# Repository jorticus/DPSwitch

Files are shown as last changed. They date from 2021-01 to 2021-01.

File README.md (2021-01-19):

# DPSwitch #

*License: CERN-OHL-S v2*

DPSwitch is a simple KVM-style device that allows you to switch Display Port & USB2.0 between two source devices (eg. a Laptop and a PC):

Mux Diagram

It is built around the HD3SS215 DP/HDMI mux chip by Texas Instruments, and has a simple flip-flop circuit and two physical buttons to select the input to route to the output. No firmware is required!

I abuse the HD3SS215's HDMI DDC lines to switch USB2.0 signals, and while the datasheet doesn't specify a maximum bandwidth for these lines, it appears to work fine. This avoids the need for a separate mux to switch USB.

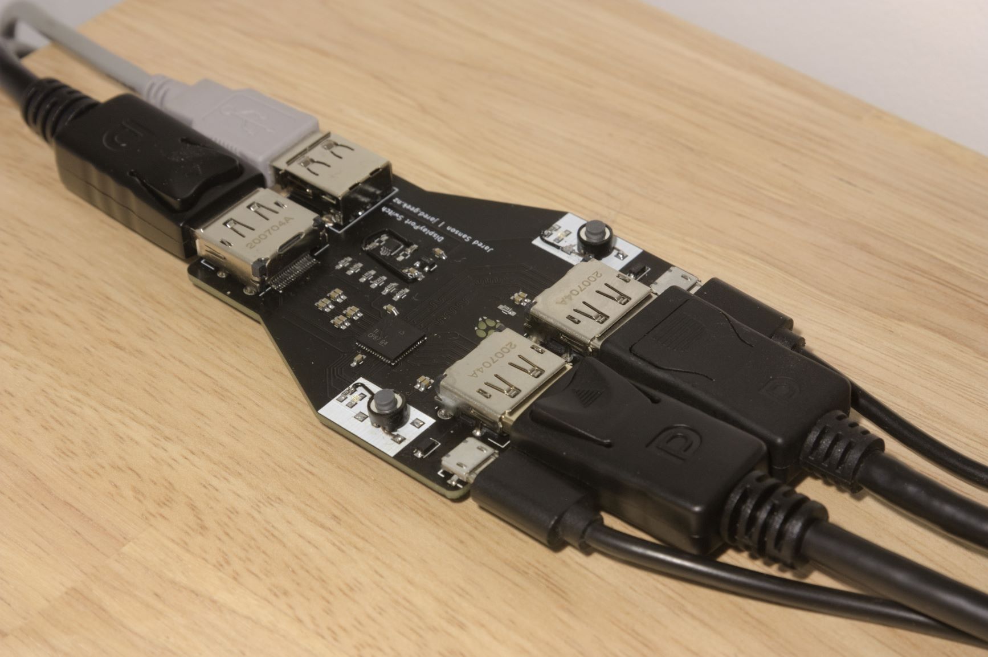
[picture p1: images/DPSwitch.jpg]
Rev1 Prototype


## Bill of Materials ##

Qty | Description               | Part Number
----|---------------------------|------------
  1 | DP/HDMI 2:1 Mux 6Gbps     | HD3SS215RTQT
  1 | Dual NAND Gate            | 74LVC2G00DC,125
  1 | 0603 Side look LED (Blue) | KPA-1606QBC-D
  2 | 0603 SMD LED (Green)      | 
  2 | Button (SMD)              | PTS645*
  1 | USB Type-A Conn (TH)      | SS-52100-001
  2 | Micro USB Conn (SMD)      | 609-5379-2-ND 
  2 | Diode                     | BAT54GWJ
  3 | DisplayPort Conn          | MOLEX 47272-0001

Plus various 0603 resistors & capacitors. See schematic.

## Manufacturing ##

Since DP operates in the GHz range, the PCB must be impedance controlled, and utilizes a 4 layer stackup. I used JLCPCB's 4-layer '[JLC7628](https://jlcpcb.com/quote/pcbOrderFaq/PCB%20Stackup)' PCB with a dielectric constant of 4.6, and a black solder mask.

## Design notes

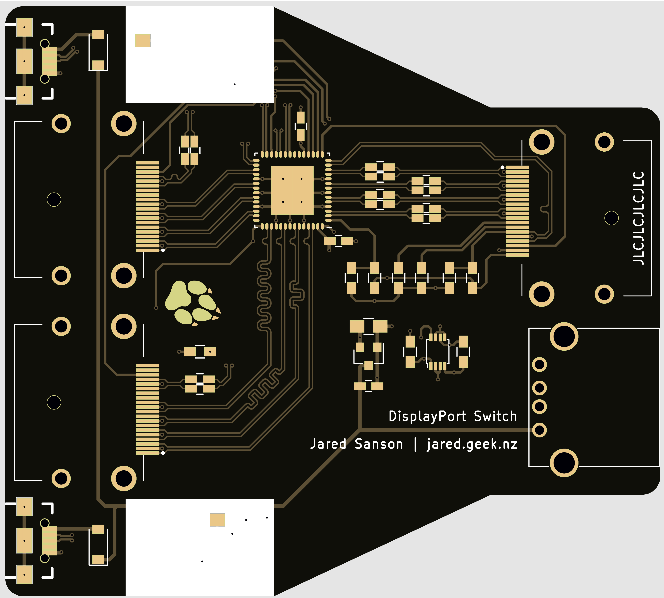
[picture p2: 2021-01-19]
pcb-front.png

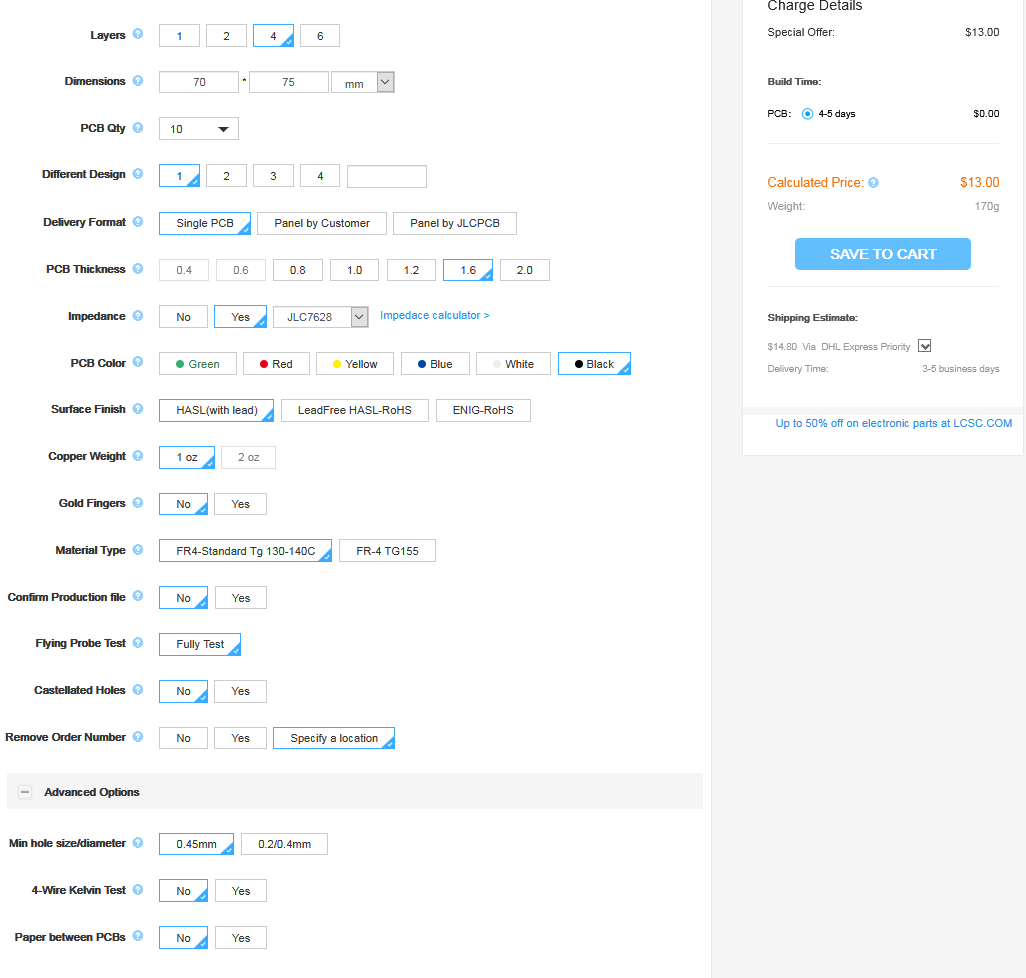
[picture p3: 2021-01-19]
JLCPCB Quote.png

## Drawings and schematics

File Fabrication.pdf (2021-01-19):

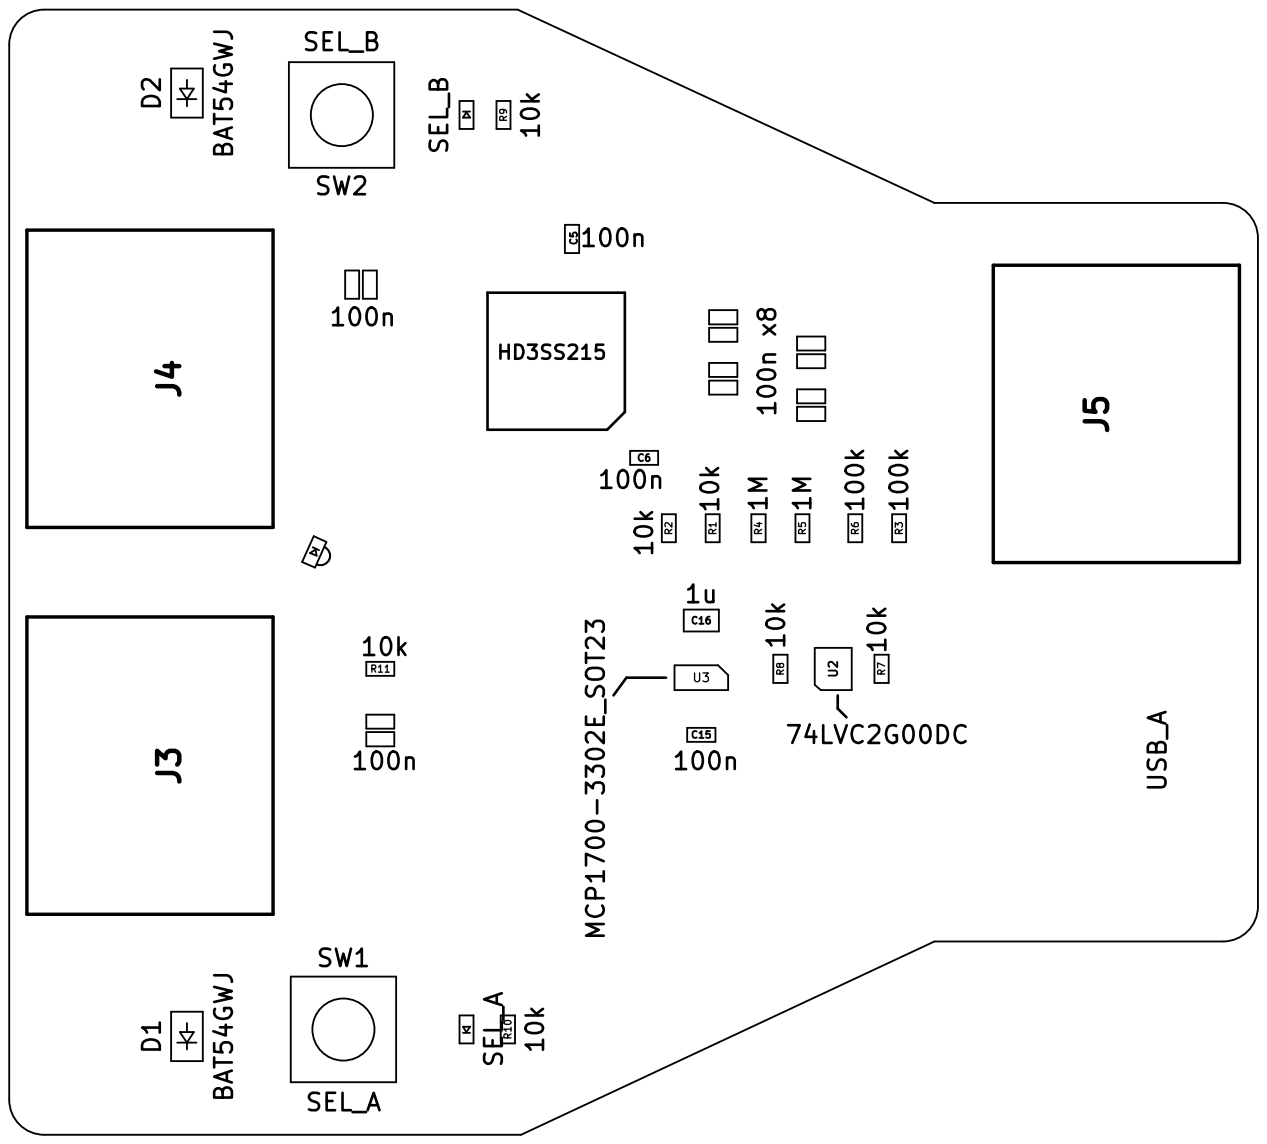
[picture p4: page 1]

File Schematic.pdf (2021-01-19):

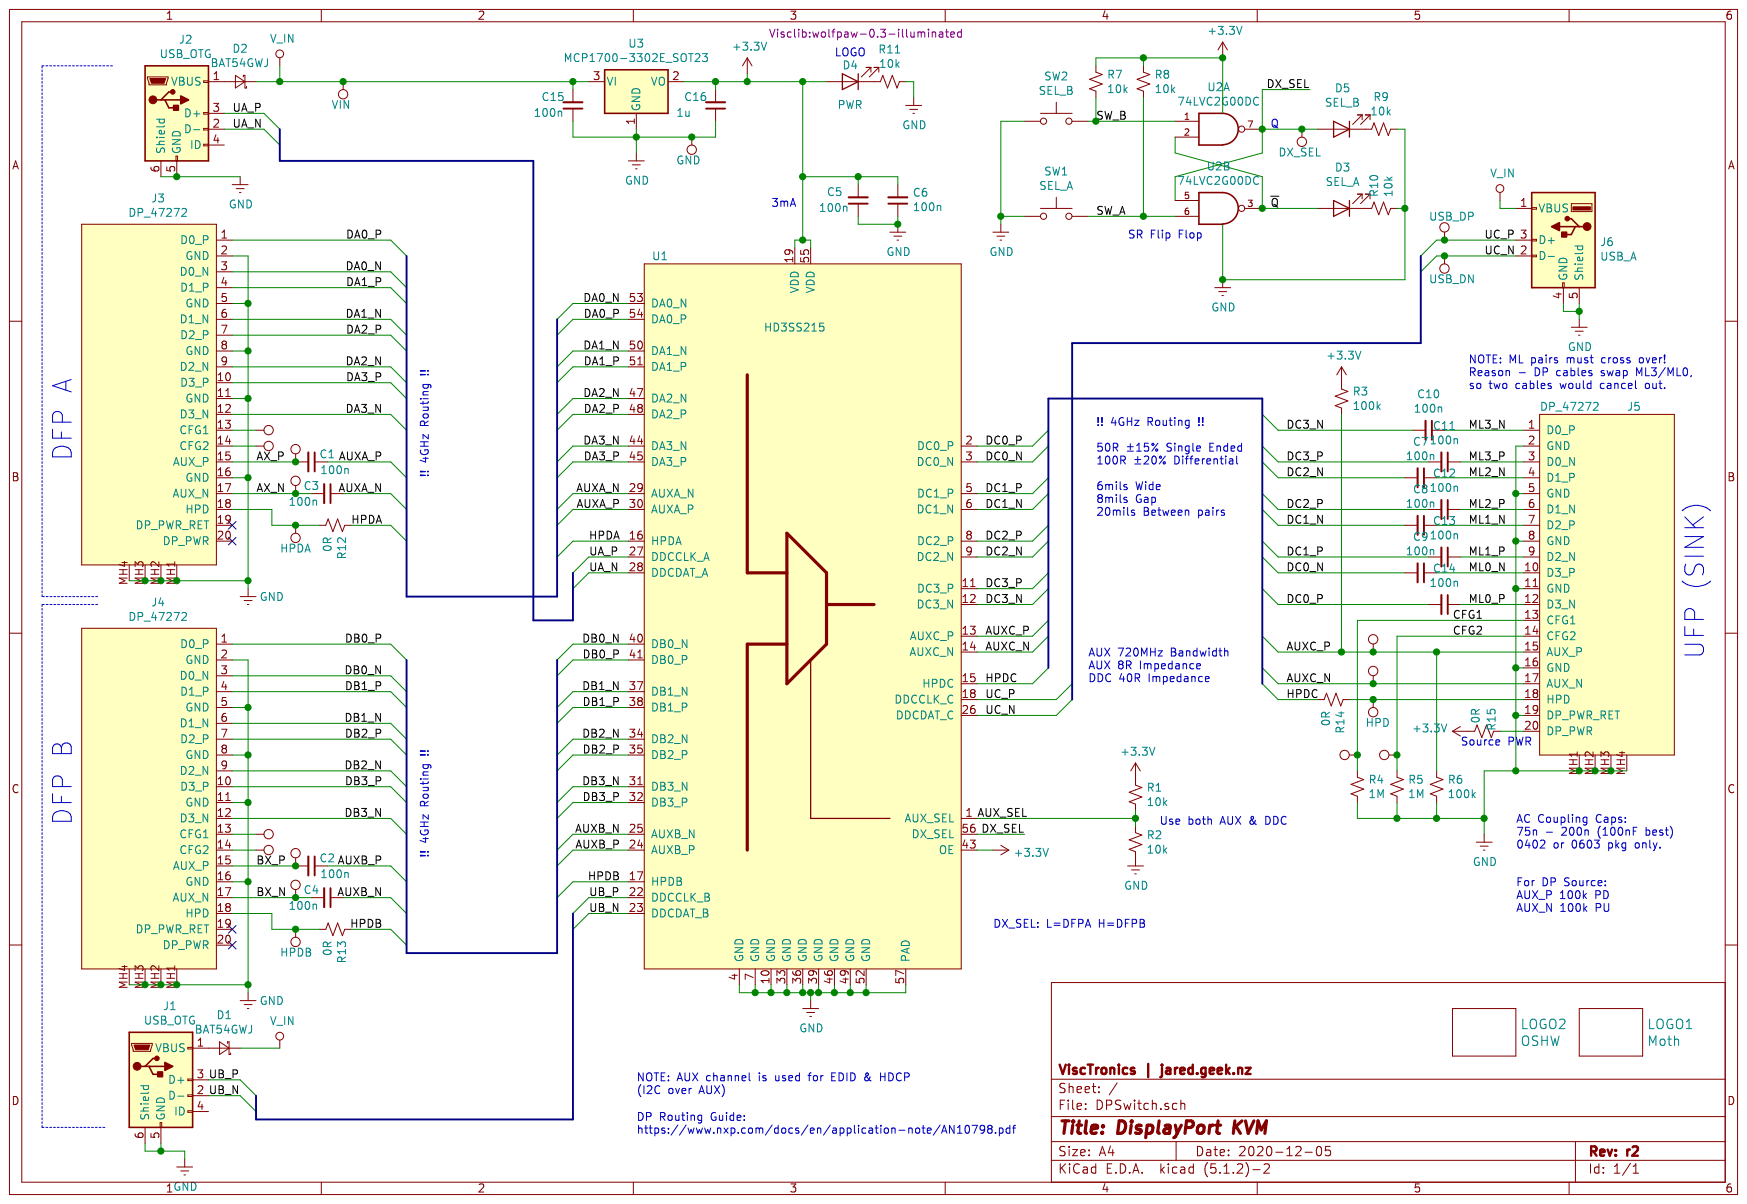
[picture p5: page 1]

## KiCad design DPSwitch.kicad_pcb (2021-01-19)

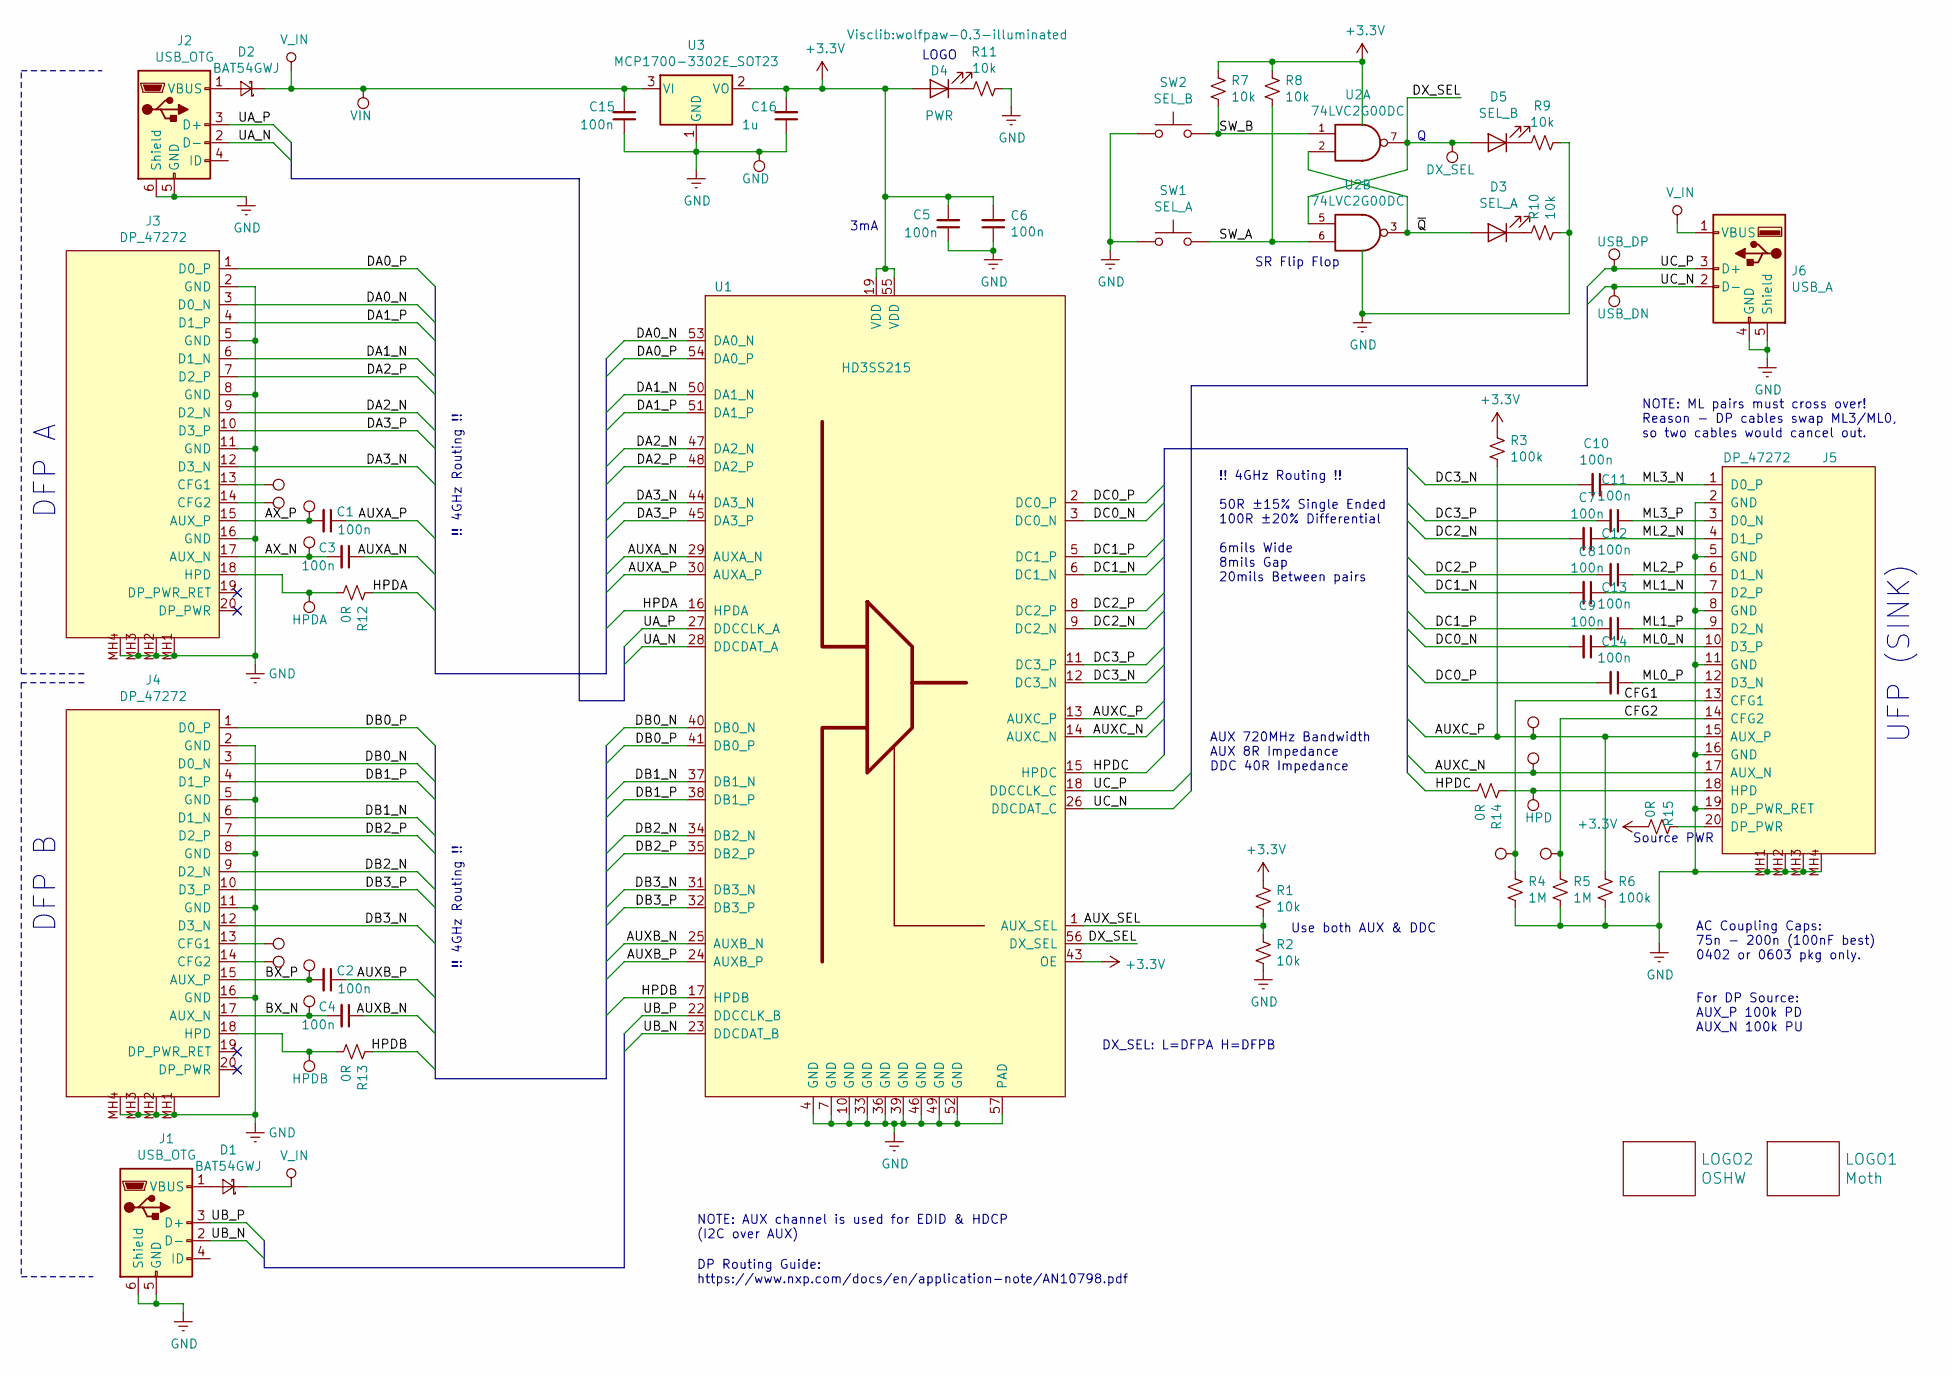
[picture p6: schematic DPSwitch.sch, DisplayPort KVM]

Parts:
C1, C2, C3, C4, C5, C6, C7, C8, C9, C10, C11, C12, C13, C14, C15: 100n; C_0603_HandSoldering
C16: 1u; C_0805_HandSoldering
D1, D2: BAT54GWJ; D_SOD-123
D3: SEL_A; LED_0603_HandSoldering
D4: PWR; wolfpaw-0.3-illuminated
D5: SEL_B; LED_0603_HandSoldering
J1, J2: USB_OTG; USB-B-MICRO-SMD
J3, J4, J5: DP_47272; 472720024
J6: USB_A
LOGO1: Moth; moth
LOGO2: OSHW; OSHW-LOGO-M
R1, R2, R7, R8, R9, R10, R11: 10k; R_0603_HandSoldering
R3, R6: 100k; R_0603_HandSoldering
R4, R5: 1M; R_0603_HandSoldering
R12, R13, R14, R15: 0R; R_0603_HandSoldering
SW1: SEL_A; SW_SPST_PTS645
SW2: SEL_B; SW_SPST_PTS645
TP1: CFG1A; TP-1MM
TP2: CFG2A; TP-1MM
TP3: CFG1B; TP-1MM
TP4: CFG2B; TP-1MM
TP5: AUXA_P; TP-1MM
TP6: AUXA_N; TP-1MM
TP7: HPDA; TP-1MM
TP8: AUXB_P; TP-1MM
TP9: AUXB_N; TP-1MM
TP10: HPDB; TP-1MM
TP11: VIN; TP-1MM
TP13: DX_SEL; TP-1MM
TP14: CFG1; TP-1MM
TP15: AUX_P; TP-1MM
TP16: AUX_N; TP-1MM
TP17: HPD; TP-1MM
TP18: CFG2; TP-1MM
TP19: USB_DP; TP-1MM
TP20: USB_DN; TP-1MM
TP21: GND; TP-1MM
U1: HD3SS215; VQFN-56_EP_7.8x7.8_Pitch0.5mm
U2: 74LVC2G00DC; VSSOP-8_2.4x2.1mm_Pitch0.5mm
U3: MCP1700-3302E_SOT23; SOT-23

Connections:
+3V3: C5.2, C6.2, C16.2, D4.2 (A), R1.1, R3.1, R7.1, R8.1, R15.2, U1.19 (VDD), U1.43 (OE), U1.55 (VDD), U2.8 (VCC), U3.2 (VO)
/AUXA_N: C3.1, U1.29 (AUXA_N)
/AUXA_P: C1.1, U1.30 (AUXA_P)
/AUXB_N: C4.1, U1.25 (AUXB_N)
/AUXB_P: C2.1, U1.24 (AUXB_P)
/AUXC_N: J5.17 (AUX_N), TP16.1, U1.14 (AUXC_N)
/AUXC_P: J5.15 (AUX_P), R3.2, R6.1, TP15.1, U1.13 (AUXC_P)
/AUX_SEL: R1.2, R2.1, U1.1 (AUX_SEL)
/AX_N: C3.2, J3.17 (AUX_N), TP6.1
/AX_P: C1.2, J3.15 (AUX_P), TP5.1
/BX_N: C4.2, J4.17 (AUX_N), TP9.1
/BX_P: C2.2, J4.15 (AUX_P), TP8.1
/CFG1: J5.13 (CFG1), R4.1, TP14.1
/CFG2: J5.14 (CFG2), R5.1, TP18.1
/DA0_N: J3.3 (D0_N), U1.53 (DA0_N)
/DA0_P: J3.1 (D0_P), U1.54 (DA0_P)
/DA1_N: J3.6 (D1_N), U1.50 (DA1_N)
/DA1_P: J3.4 (D1_P), U1.51 (DA1_P)
/DA2_N: J3.9 (D2_N), U1.47 (DA2_N)
/DA2_P: J3.7 (D2_P), U1.48 (DA2_P)
/DA3_N: J3.12 (D3_N), U1.44 (DA3_N)
/DA3_P: J3.10 (D3_P), U1.45 (DA3_P)
/DB0_N: J4.3 (D0_N), U1.40 (DB0_N)
/DB0_P: J4.1 (D0_P), U1.41 (DB0_P)
/DB1_N: J4.6 (D1_N), U1.37 (DB1_N)
/DB1_P: J4.4 (D1_P), U1.38 (DB1_P)
/DB2_N: J4.9 (D2_N), U1.34 (DB2_N)
/DB2_P: J4.7 (D2_P), U1.35 (DB2_P)
/DB3_N: J4.12 (D3_N), U1.31 (DB3_N)
/DB3_P: J4.10 (D3_P), U1.32 (DB3_P)
/DC0_N: C9.2, U1.3 (DC0_N)
/DC0_P: C14.2, U1.2 (DC0_P)
/DC1_N: C8.2, U1.6 (DC1_N)
/DC1_P: C13.2, U1.5 (DC1_P)
/DC2_N: C7.2, U1.9 (DC2_N)
/DC2_P: C12.2, U1.8 (DC2_P)
/DC3_N: C10.2, U1.12 (DC3_N)
/DC3_P: C11.2, U1.11 (DC3_P)
/DX_SEL: D5.2 (A), TP13.1, U1.56 (DX_SEL), U2.5, U2.7
/HPDA: R12.1, U1.16 (HPDA)
/HPDB: R13.1, U1.17 (HPDB)
/HPDC: R14.2, U1.15 (HPDC)
/ML0_N: C9.1, J5.10 (D3_P)
/ML0_P: C14.1, J5.12 (D3_N)
/ML1_N: C8.1, J5.7 (D2_P)
/ML1_P: C13.1, J5.9 (D2_N)
/ML2_N: C7.1, J5.4 (D1_P)
/ML2_P: C12.1, J5.6 (D1_N)
/ML3_N: C10.1, J5.1 (D0_P)
/ML3_P: C11.1, J5.3 (D0_N)
/SW_A: R8.2, SW1.2, U2.6
/SW_B: R7.2, SW2.2, U2.1
/UA_N: J2.2 (D-), U1.28 (DDCDAT_A)
/UA_P: J2.3 (D+), U1.27 (DDCCLK_A)
/UB_N: J1.2 (D-), U1.23 (DDCDAT_B)
/UB_P: J1.3 (D+), U1.22 (DDCCLK_B)
/UC_N: J6.2 (D-), TP20.1, U1.26 (DDCDAT_C)
/UC_P: J6.3 (D+), TP19.1, U1.18 (DDCCLK_C)
/~Q: D3.2 (A), U2.2, U2.3
GND: C5.1, C6.1, C15.1, C16.1, J1.5 (GND), J1.6 (Shield), J2.5 (GND), J2.6 (Shield), J3.2 (GND), J3.5 (GND), J3.8 (GND), J3.11 (GND), J3.16 (GND), J3.MH1, J3.MH2, J3.MH3, J3.MH4, J4.2 (GND), J4.5 (GND), J4.8 (GND), J4.11 (GND), J4.16 (GND), J4.MH1, J4.MH2, J4.MH3, J4.MH4, J5.2 (GND), J5.5 (GND), J5.8 (GND), J5.11 (GND), J5.16 (GND), J5.19 (DP_PWR_RET), J5.MH1, J5.MH2, J5.MH3, J5.MH4, J6.4 (GND), J6.5 (Shield), R2.2, R4.2, R5.2, R6.2, R9.1, R10.2, R11.1, SW1.1, SW2.1, TP21.1, U1.4 (GND), U1.7 (GND), U1.10 (GND), U1.33 (GND), U1.36 (GND), U1.39 (GND), U1.46 (GND), U1.49 (GND), U1.52 (GND), U1.57 (PAD), U2.4 (GND), U3.1 (GND)
unnamed: D1.2 (A), J1.1 (VBUS)
unnamed: D2.2 (A), J2.1 (VBUS)
unnamed: D3.1 (K), R10.1
unnamed: D4.1 (K), R11.2
unnamed: D5.1 (K), R9.2
unnamed: J3.13 (CFG1), TP1.1
unnamed: J3.14 (CFG2), TP2.1
unnamed: J3.18 (HPD), R12.2, TP7.1
unnamed: J4.13 (CFG1), TP3.1
unnamed: J4.14 (CFG2), TP4.1
unnamed: J4.18 (HPD), R13.2, TP10.1
unnamed: J5.18 (HPD), R14.1, TP17.1
unnamed: J5.20 (DP_PWR), R15.1
VDD: C15.2, D1.1 (K), D2.1 (K), J6.1 (VBUS), TP11.1, U3.3 (VI)

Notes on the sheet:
UFP (SINK)
DFP A
DFP B
For DP Source: AUX_P 100k PD AUX_N 100k PU
DX_SEL: L=DFPA H=DFPB
AUX 720MHz Bandwidth AUX 8R Impedance DDC 40R Impedance
NOTE: AUX channel is used for EDID & HDCP (I2C over AUX)
AC Coupling Caps: 75n - 200n (100nF best) 0402 or 0603 pkg only.
Use both AUX & DDC
!! 4GHz Routing !!
NOTE: ML pairs must cross over! Reason - DP cables swap ML3/ML0, so two cables would cancel out.
Source PWR
3mA
!! 4GHz Routing !! 50R ±15% Single Ended 100R ±20% Differential 6mils Wide 8mils Gap 20mils Between pairs
DP Routing Guide: https://www.nxp.com/docs/en/application-note/AN10798.pdf
LOGO
SR Flip Flop

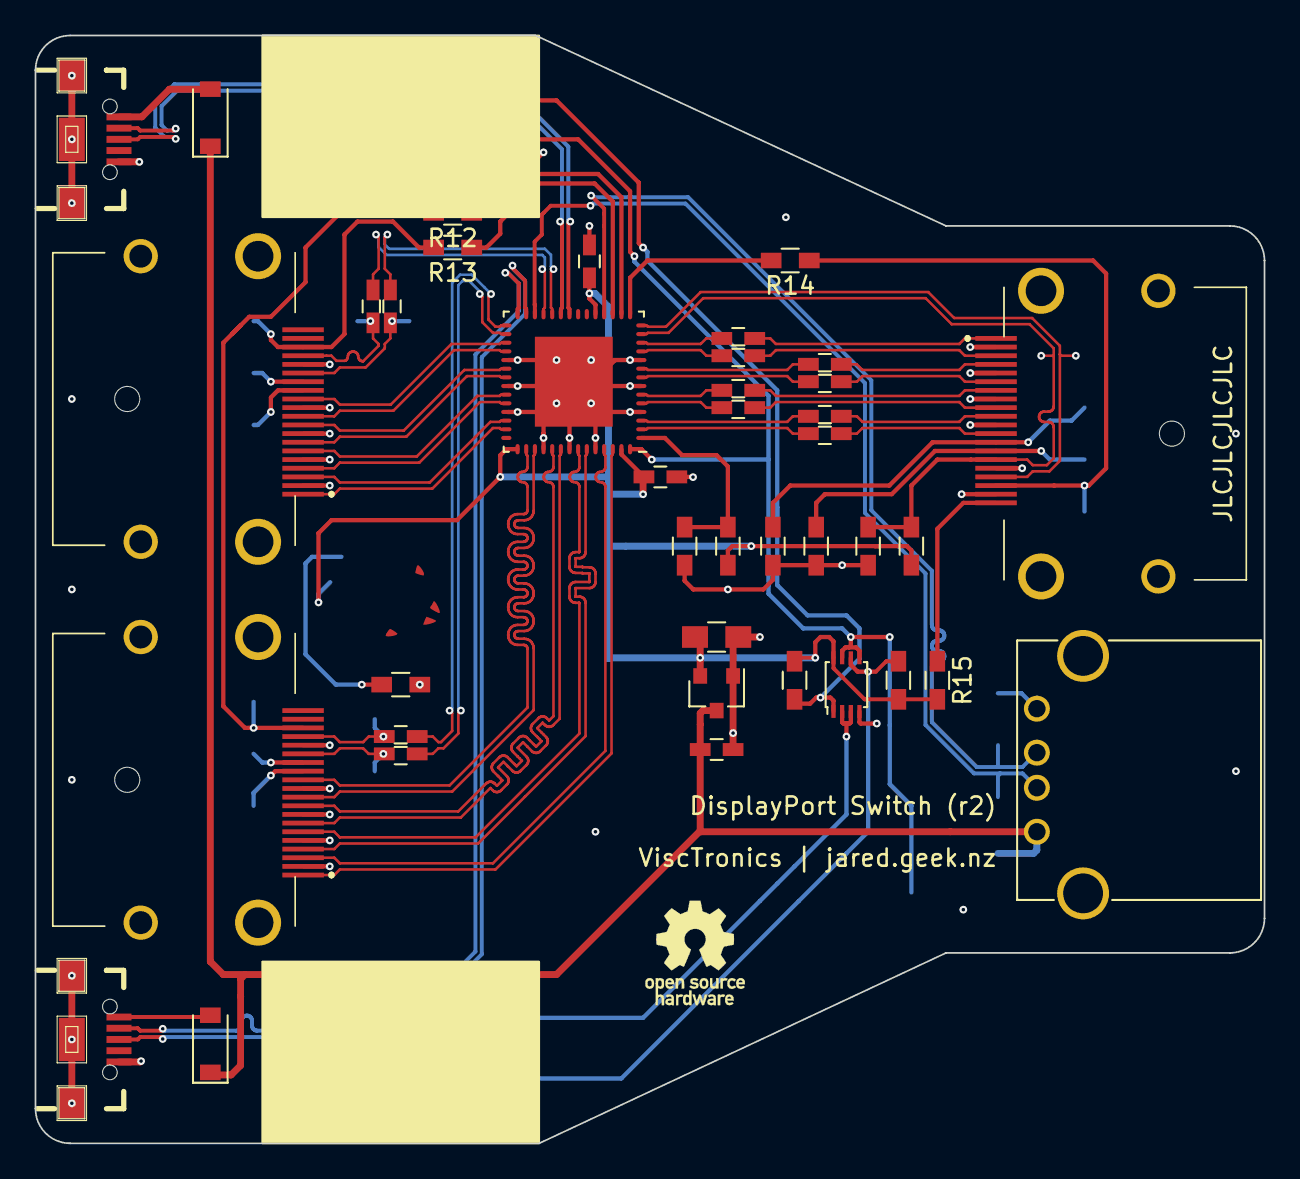
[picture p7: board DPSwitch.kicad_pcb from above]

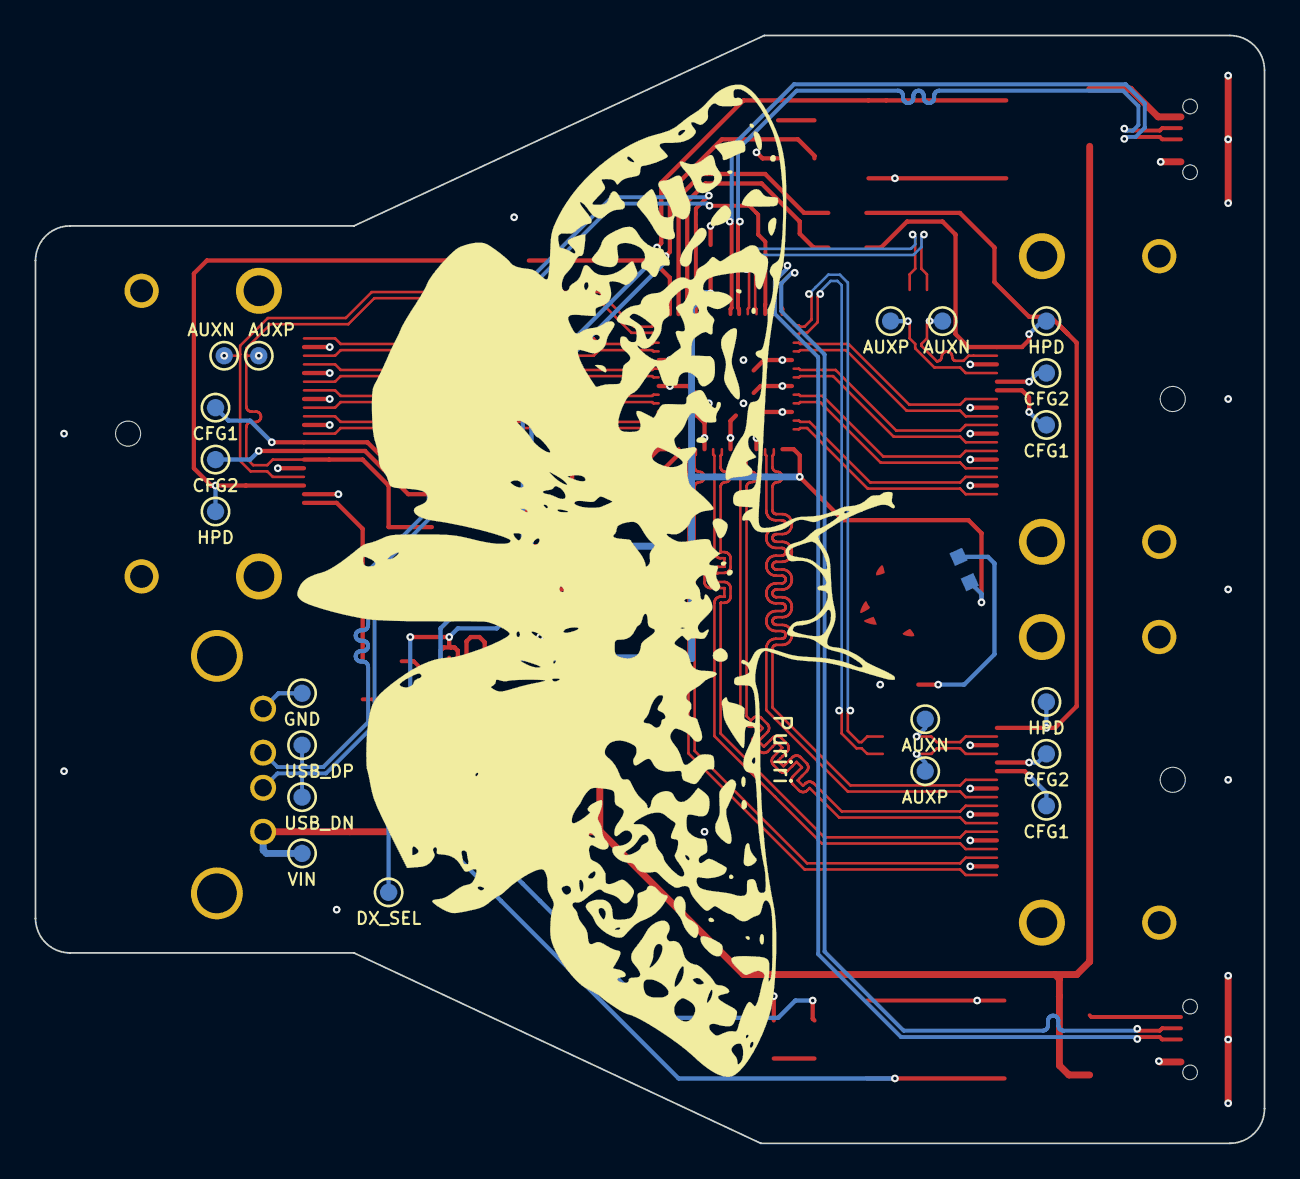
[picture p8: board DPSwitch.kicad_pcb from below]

Board: 4 copper layers, 71.0 x 64.0 mm, 69 parts (21 on the bottom side), 74 nets.

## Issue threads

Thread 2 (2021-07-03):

DP connectors are loose causing signal integrity issues

jorticus, 2021-07-03:
The DP connectors I bought do not seat securely, and there is significant wobble in them. This seems to be causing signal integrity issues with DP

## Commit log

2021-01-19 Rev1 for manufacture
    [DPSwitch.kicad_pcb, DPSwitch.sch]
2021-01-19 Added moth
    [DPSwitch.kicad_pcb, DPSwitch.sch]
2021-01-19 Final gerbers rev1.2
    [DPSwitch-B_Cu.gbr, DPSwitch-B_Mask.gbr, DPSwitch-B_SilkS.gbr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]
2021-01-19 Tidy up fabrication layer
    [DPSwitch.kicad_pcb]
2021-01-19 r2 - Swap USB A/B inputs, fix inverted flip-flop logic
    [DPSwitch.kicad_pcb, DPSwitch.sch]
2021-01-19 Add testpads, 0R resistors to allow reconfiguration, and OSHW logo
    [DPSwitch.kicad_pcb, DPSwitch.sch]
2021-01-19 Rev2 for manufacture
    [DPSwitch-B_Cu.gbr, DPSwitch-B_Mask.gbr, DPSwitch-B_SilkS.gbr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]
